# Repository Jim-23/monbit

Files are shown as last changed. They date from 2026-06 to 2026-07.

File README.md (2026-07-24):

# Monbit

A tiny ESP32-based digital monster pet with an e-ink display that evolves over time based on care, sleep cycles, and randomness.

<p align="center">
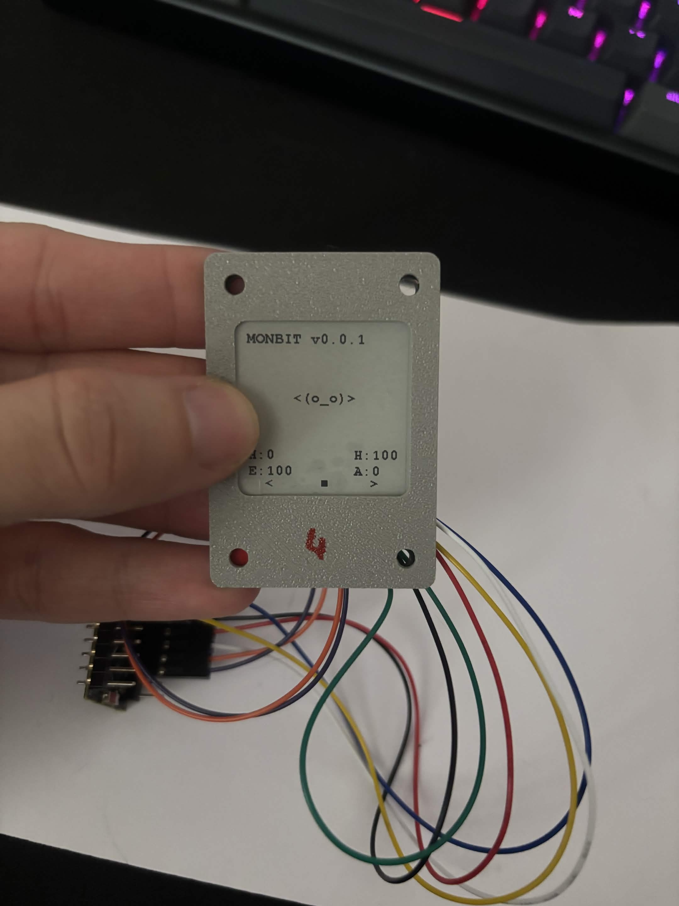
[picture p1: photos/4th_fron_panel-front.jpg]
Monbit front panel
  
</p>

## Motivation

Monbit is a personal project created to learn embedded development, hardware prototyping, and product design.

The goal is not only to create a device, but also to explore the full product development process. From firmware and electronics to CAD design and physical prototype.

I want to document the entire journey, sharing both successes and failures, to create a resource for others interested in similar projects.

---

### Documentation

- [Roadmap](./ROADMAP.md)
- [Development Log](./DEVLOG.md)
- [Hardware Notes](./hardware/hw-notes.md)
- [Game Design](./docs/game_design.md)
- [UI Design](./docs/ui_design.md)

## Current Progress

Current Version: `v0.0.4` (2026-07-13)

### Firmware
- [x] ESP32 bring-up
- [x] Project architecture (modular source files)
- [x] E-Ink display communication
- [x] Basic UI rendering
- [x] Partial display refresh
- [x] 3-button input system
- [x] Button debouncing
- [x] Monster state system
- [x] Monster actions (Feed / Play / Sleep)
- [x] Automatic monster tick system
- [x] Persistent storage (save/load)
- [x] Audio subsystem
- [x] Menu system
- [ ] Monster logic (name, personality, reactions)
- [ ] Battery management
- [ ] Deep sleep
- [ ] Sprite rendering

### Hardware
- [x] Components selected
- [x] ESP32 tested
- [x] E-Ink display tested
- [x] Buttons tested (breadboard)
- [x] First enclosure front prototype designed (front lid, far from final)
- [x] Audio amplifier connected
- [x] Speaker connected
- [ ] Battery integrated
- [ ] Charging module integrated
- [ ] Power switch integrated
- [ ] Accelerometer integrated
- [ ] Permanent wiring
- [ ] First fully assembled prototype
- [ ] Final enclosure designed

### Gameplay
- [x] Basic monster stats
- [x] Monster actions
- [x] Time-based stat changes
- [x] Beep when action is done
- [ ] Naming the monster
- [ ] Monster sprite and animations
- [x] Monster moods and states
- [ ] Growth/aging system
- [ ] Evolution
- [ ] Random events
- [ ] Game balancing

### Documentation
- [x] README
- [x] Roadmap
- [x] Devlog
- [x] Project versioning
- [ ] Wiring diagrams
- [ ] Hardware BOM
- [ ] Build instructions

## Milestones

### v0.0.1 — Hello Hardware

Completed:
- ESP32-C3 configured with PlatformIO
- USB serial debugging enabled
- E-Ink display connected and initialised
- First successful display render (`MONBIT v0.0.1`)

Update:
- basic GUI setup
- connected first button

### v0.0.2 — Buttons

Completed:
- Buttons are detected and affect                    the stats
  - LEFT button => eat
  - MIDDLE button => play
  - RIGHT button => sleep
- Screen has two options for refresh - full or partial
- When the button is pressed, the screen refreshes partially (without the big blink)
- Happiness renamed to Fun

### v0.0.3 - Storage

Completed:
- Every tick (currently 10 seconds), the hunger, fun and energy are changed by 1
- Every time the button is pressed, the current state of the Monster is saved to Flash
- When rebooted, the data is loaded

### v0.0.4 - Audio

Completed:
- Audio subsystem added
- Beep when button is pressed

### v0.0.5 - Menu

Completed:
- Menu system added
- Menu can be navigated with the buttons
- So far only mock settings are available in the menu (no actual functionality yet)

### v0.0.6 - Monster Logic

Completed:
- Moods and states were added
- Different monster visuals for the specific state/mood

## Hardware

Core components:

- ESP32-C3 SuperMini ?
- WeAct 1.54" E-Ink Display
- 500mAh LiPo Battery
- TP4056 USB-C Charging Module ?

- Tactile Buttons
- MAX98357A Audio Amplifier
- Speaker
- MPU6050 Accelerometer

## Software

Development environment:

- C++
- Arduino Framework
- PlatformIO
- Visual Studio Code

Libraries:

- GxEPD2
- FreeMonoBold0pt7bt
- i2s

## Gallery

### Wiring & Setup

<p align="center">
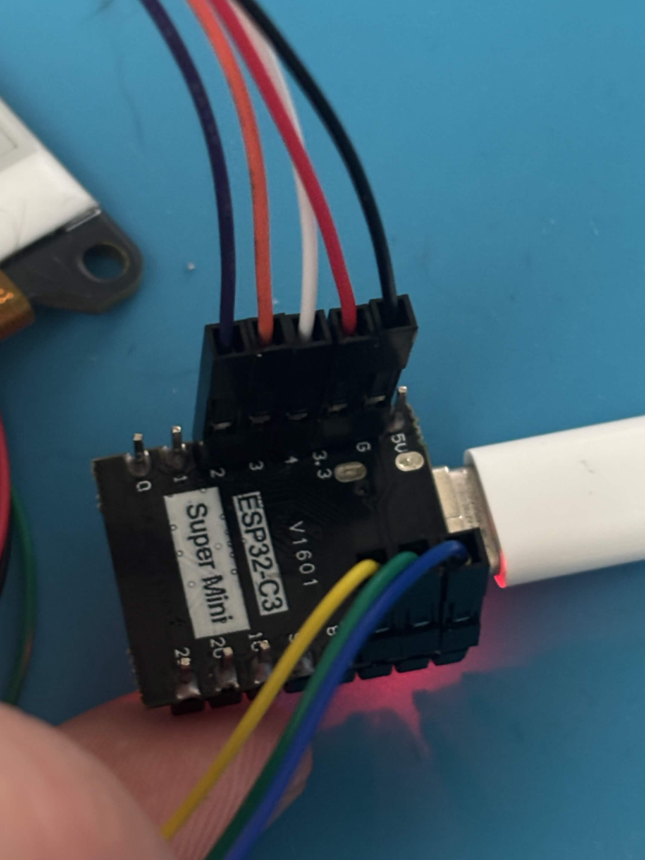
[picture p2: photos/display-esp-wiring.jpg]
ESP32 to e-ink display wiring
  
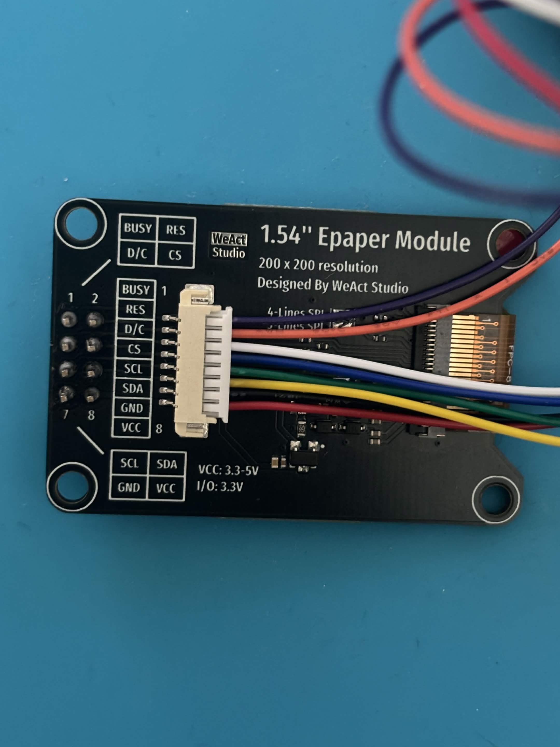
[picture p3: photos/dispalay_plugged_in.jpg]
Display plugged in
  
</p>
<p align="center">
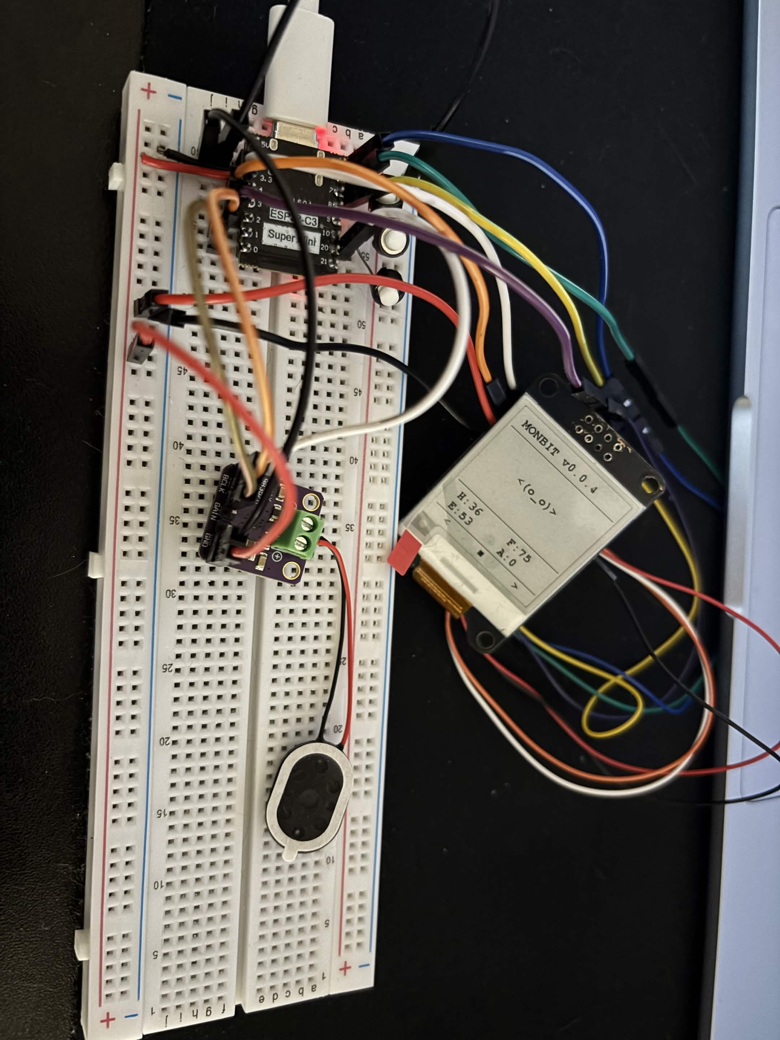
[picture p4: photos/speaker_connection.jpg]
Speaker connection (spaghetti monster has been created)
  
</p>

### Display & GUI

<p align="center">
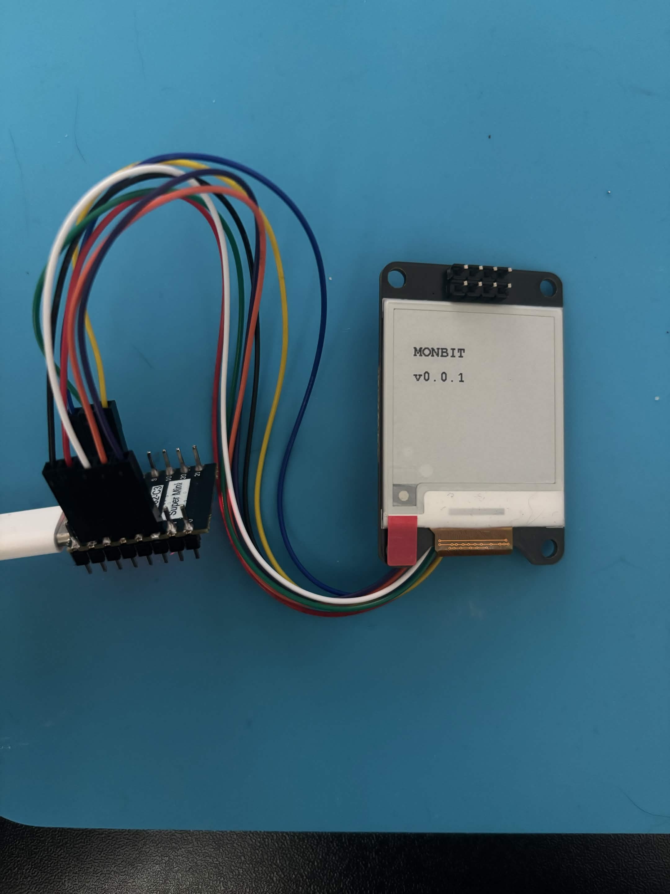
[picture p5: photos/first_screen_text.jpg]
First screen text render
  
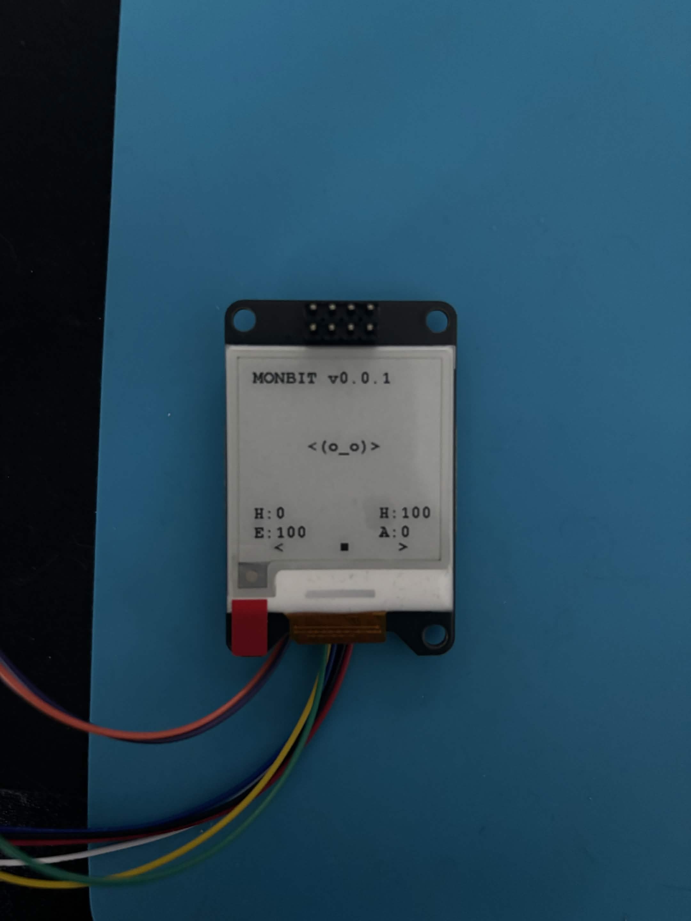
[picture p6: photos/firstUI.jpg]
First UI rendered on the e-ink display
  
</p>
<p align="center">
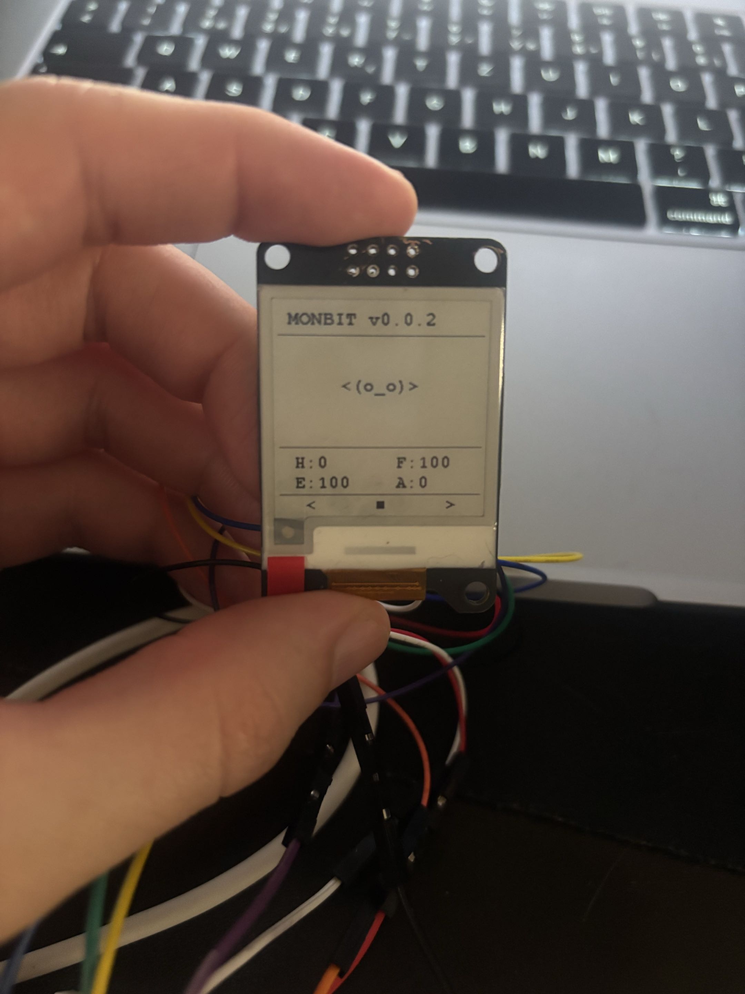
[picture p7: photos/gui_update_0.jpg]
GUI update
  
</p>
<p align="center">
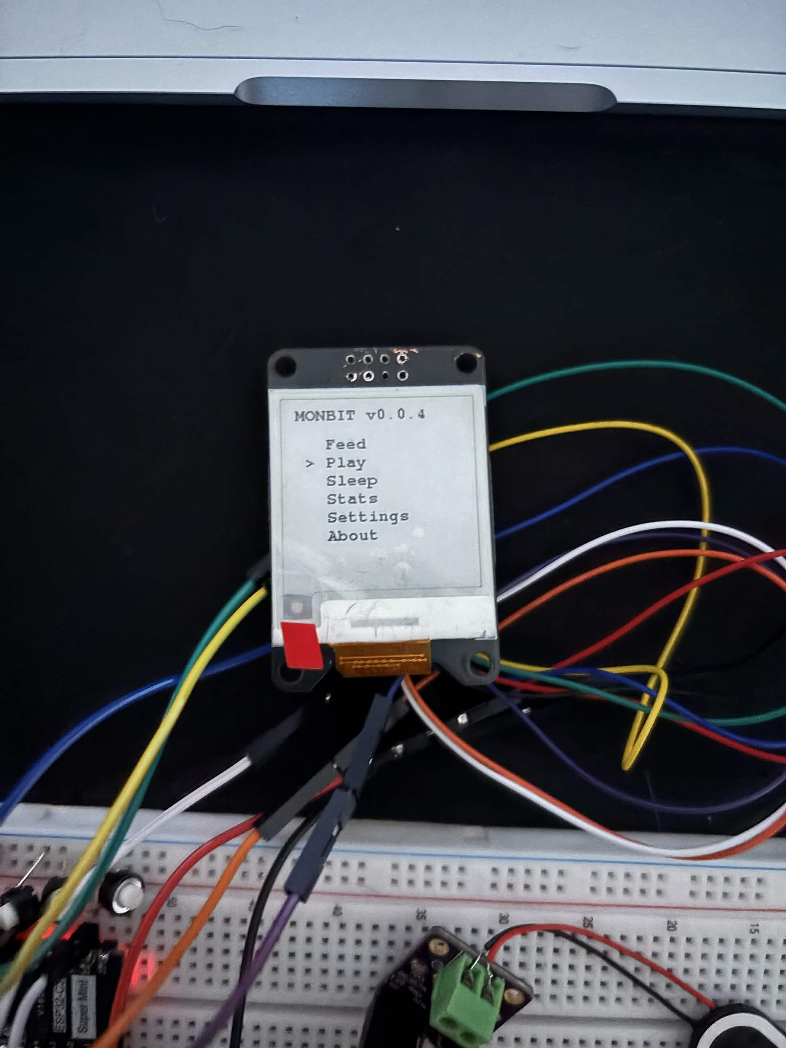
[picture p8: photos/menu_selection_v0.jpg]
Menu
  
</p>

### Buttons

<p align="center">
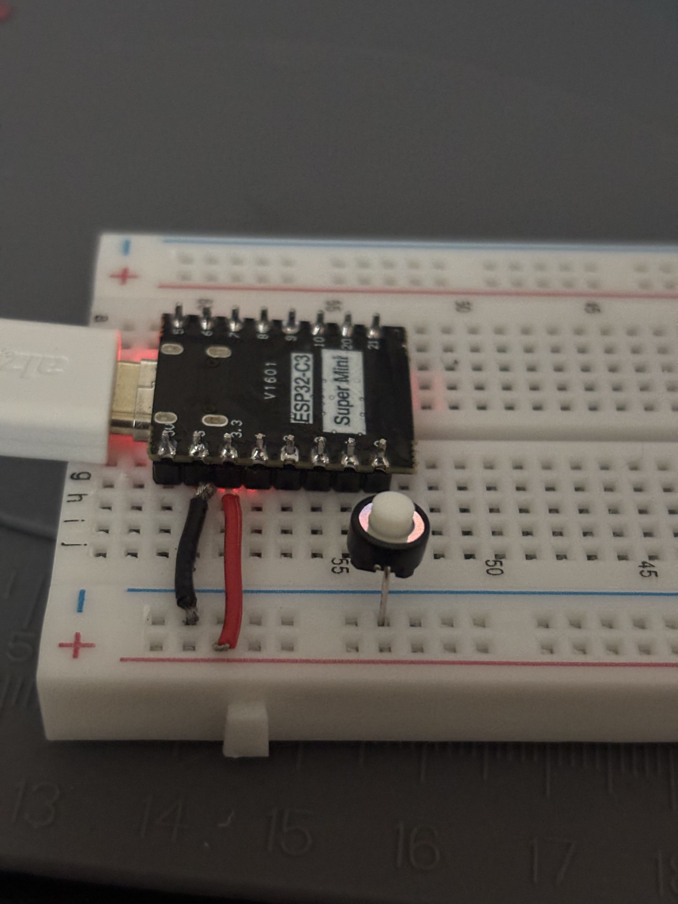
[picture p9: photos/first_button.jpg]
First button wired
  
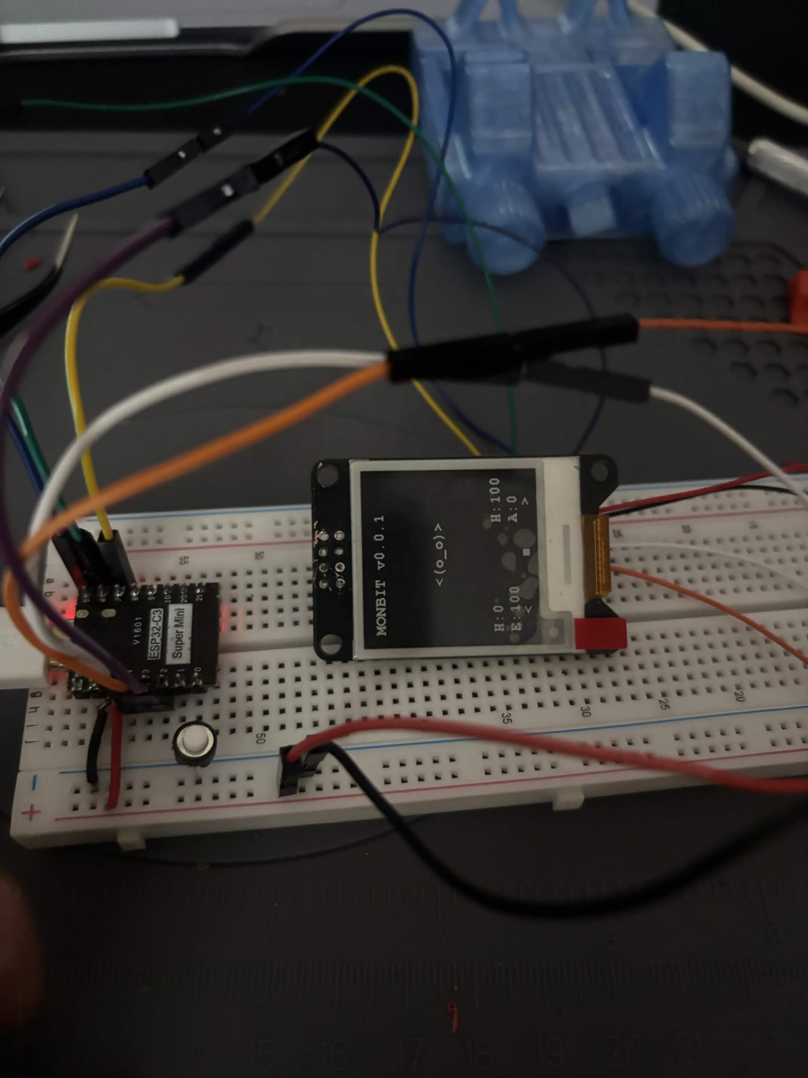
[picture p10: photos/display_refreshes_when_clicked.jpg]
Display refreshing on button click
  
</p>
<p align="center">
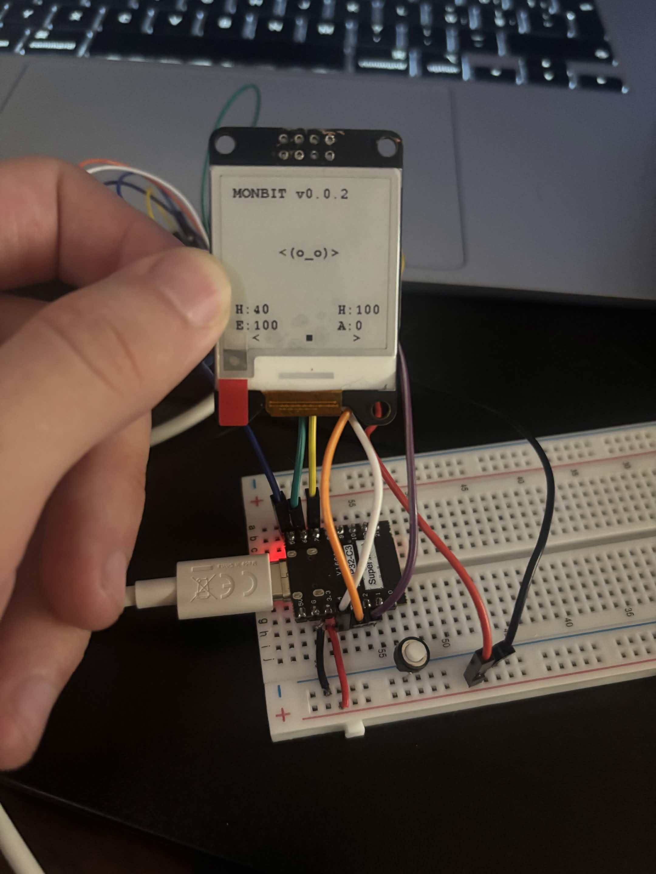
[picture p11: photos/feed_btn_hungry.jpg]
Feed button - hungry state
  
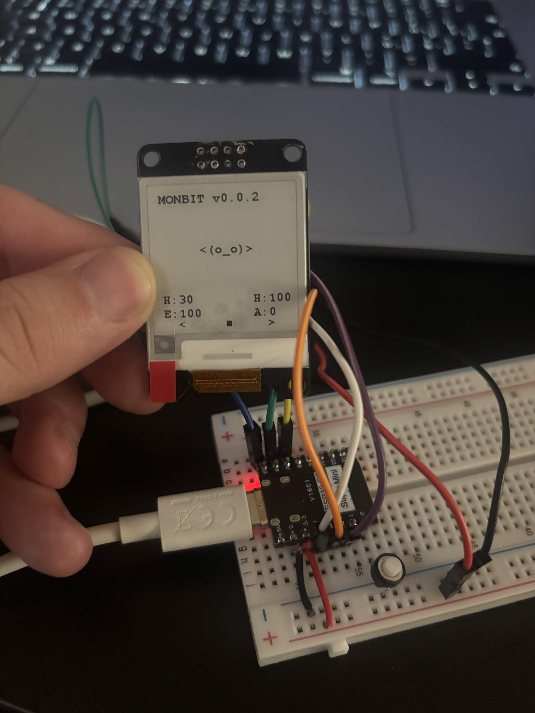
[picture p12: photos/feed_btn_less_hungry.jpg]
Feed button - less hungry state
  
</p>
<p align="center">
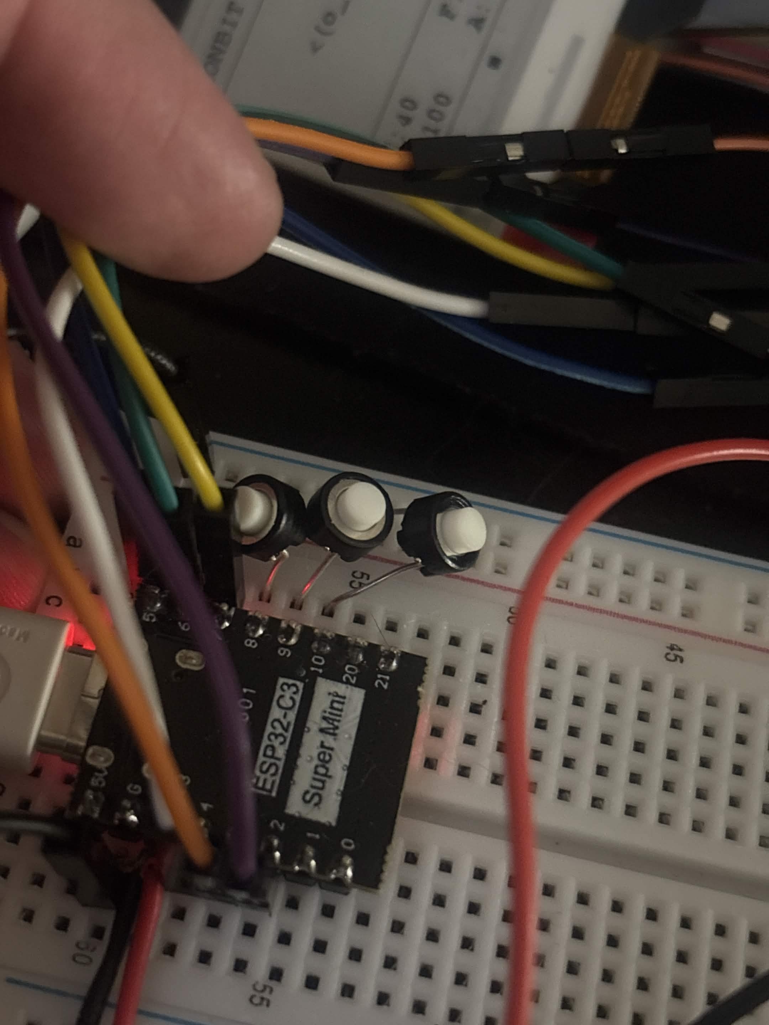
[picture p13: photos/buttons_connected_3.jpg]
Three buttons connected
  
</p>

### Enclosure

<p align="center">
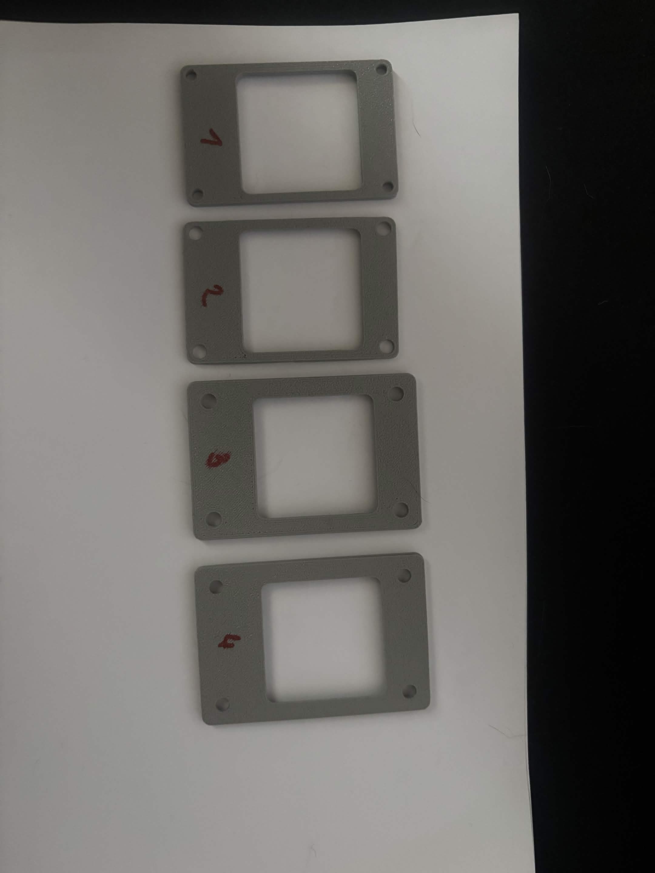
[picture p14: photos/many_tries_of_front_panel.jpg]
Multiple front panel iterations
  
</p>
<p align="center">
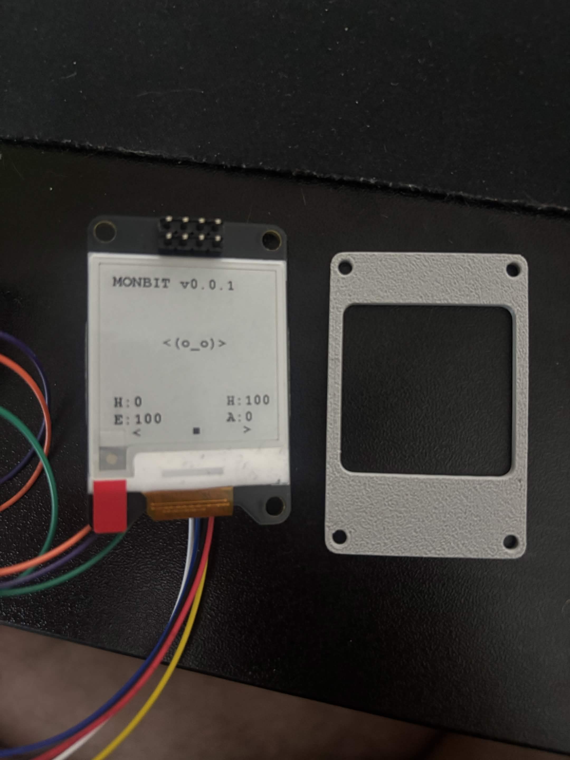
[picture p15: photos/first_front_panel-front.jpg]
First front panel - front
  
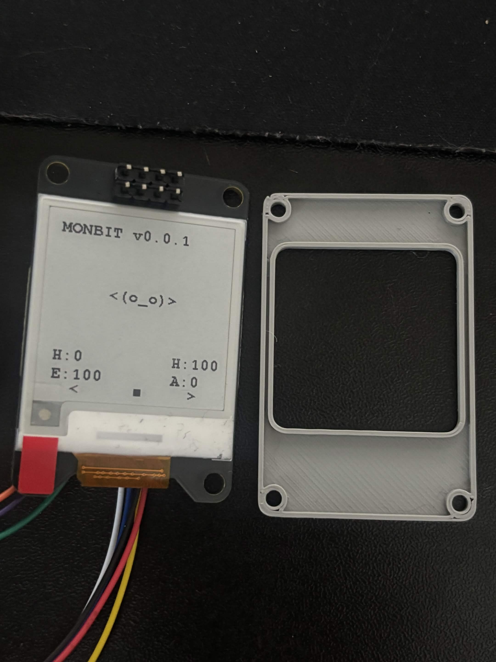
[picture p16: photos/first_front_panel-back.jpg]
First front panel - back
  
</p>
<p align="center">
  Front panel - front
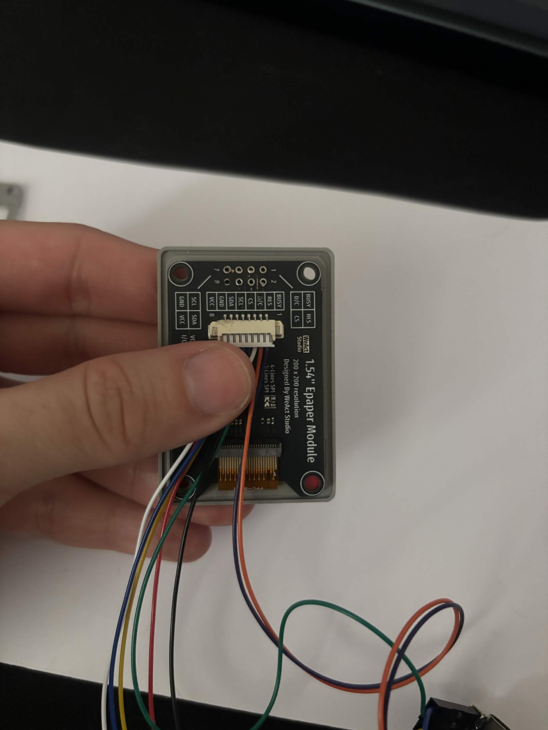
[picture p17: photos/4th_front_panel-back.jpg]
Front panel - back
  
</p>

## Repository Structure

```
monbit/
├── firmware/     # ESP32 firmware (PlatformIO)
│   ├── include/
│   ├── lib/
│   ├── src/
|   |   ├── debug/ # code used for debugging and testing
│   ├── test/
│   └── platformio.ini
├── hardware/     # Hardware notes & measurements
│   ├── hardware_notes.md
│   └── measurements.md
├── design/       # CAD files (enclosure STLs)
├── docs/         # Design notes
│   ├── game_design.md
│   └── ui_design.md
├── photos/       # Build & progress photos
├── DEVLOG.md
├── ROADMAP.md
├── LICENSE
└── README.md
```

---

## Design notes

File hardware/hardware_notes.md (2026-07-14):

# ESP32-C3 SuperMini

## ESP board pinout
ESP32-C3 SuperMini pinout

| Pin | Describtion | Connection |
|-----|---|---|
| 5V | 5V  | - |
| G | GND | Ground |
| 3V3 | 3.3V | Power |
| 4 | GPIO4 | Display DC |
| 3 | GPIO3 | Display RES |
| 2 | GPIO2 | Display BUSY |
| 1 | GPIO1 | Audio BCLK |
| 0 | GPIO0 | Audio DIN |
| 5 | GPIO5 | Display CS |
| 6 | GPIO6 | Display SCL |
| 7 | GPIO7 | Display SDA |
| 8 | GPIO8 | Left Button |
| 9 | GPIO9 | Middle Button |
| 10 | GPIO10 | Right Button |
| 20 | GPIO20 | Audio LRC (WS) |
| 21 | GPIO21 | - |

## Upload

Board:
esp32-c3-devkitm-1

Monitor speed:
115200

USB:
Works on macOS with data-capable USB-C cable

## Buttons - care for monster
| Button | ESP32-C3 |
|---|---|
| Left | GPIO8 |
| Middle | GPIO9 |
| Right | GPIO10 |
| Other Pin | GND |

## Display

Display:
WeAct 1.54" E-Paper

### Display Wiring to ESP

| WeAct E-Ink | ESP32-C3 |
|---|---|
| VCC | 3.3V |
| GND | GND |
| SDA | GPIO7 |
| SCL | GPIO6 |
| CS | GPIO5 |
| DC | GPIO4 |
| RES | GPIO3 |
| BUSY | GPIO2 |

PlatformIO:

build_flags =
    -DARDUINO_USB_MODE=1
    -DARDUINO_USB_CDC_ON_BOOT=1

Driver:

- GxEPD2_154_GDEY0154D67

SPI:

- SPI.begin(6, -1, 7, 5);

### Audio wiring to ESP

| MAX98357A | ESP32-C3 |
|---|---|
| VIN | 3.3V |
| GND | GND |
| DIN | GPIO0 |
| BCLK | GPIO1 |
| LRC (WS) | GPIO20 |
| SD | NC |
| GAIN | NC |
| SPK+ | Speaker + |
| SPK- | Speaker - |

#### Working Configuration

```cpp
Sample Rate          : 22050 Hz
Bits Per Sample      : 16-bit
DMA Buffer Count     : 8
DMA Buffer Length    : 512
Channel Format       : I2S_CHANNEL_FMT_RIGHT_LEFT
Communication Format : I2S_COMM_FORMAT_STAND_I2S
Waveform             : Sine
Amplitude            : 75%
```

> **Note:** 16000 Hz also produced clean audio, but 22050 Hz was selected as the project default.

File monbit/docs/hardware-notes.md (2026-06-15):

# ESP32-C3 SuperMini

## Upload

Board:
esp32-c3-devkitm-1

Monitor speed:
115200

USB:
Works on macOS with data-capable USB-C cable

## Display

Display:
WeAct 1.54" E-Paper

Pins:

VCC -> 3.3V
GND -> GND
SDA -> GPIO7
SCL -> GPIO6
CS -> GPIO5
D/C -> GPIO4
RES -> GPIO3
BUSY -> GPIO2

PlatformIO:

build_flags =
    -DARDUINO_USB_MODE=1
    -DARDUINO_USB_CDC_ON_BOOT=1

Driver:

GxEPD2_154_GDEY0154D67

SPI:

SPI.begin(6, -1, 7, 5);

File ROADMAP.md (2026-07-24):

# Roadmap

## 0.0.1 — Hello Hardware

### Goal

* ESP32 boots
* Serial prints work
* Display shows something

### Hardware

* ESP32-C3 Development Board (WiFi + Bluetooth)
* WeAct 1.54" E-Paper Module (SPI, Black/White)

### Done When

* Code uploads successfully
* Serial output works
* Display shows text or image

**Status:** Completed

---

## 0.0.2 — Input System

### Goal

* Wire buttons
* Wire power switch
* Detect button presses
* When button pressed, do something to monster (feed it for example)

Example Stats

* Hunger
* Fun
* Energy

### Hardware

* SKRGAED010 ALPS Tact Switch

### Done When
* Basic monster stats
* Simple interactions
  
* Buttons modify stats
* Display updates values

**Status:** Completed

---

## 0.0.3 — Basic monster + Memory System

### Goal:

- Monster state changes over time
- Save current state to flash
- Load state after reboot

### Done when:
- Power off device
- Power on device
- Monster stats are restored

Example:

* Hunger
* Fun
* Energy

**Status:** Completed

---

## 0.0.4 — Sound System

### Goal

* Play simple sounds
* Confirm actions with sound

### Hardware

* MAX98357A Audio Amplifier Module
* 15x3.5mm Mini Round Speaker 8Ω 0.5W

### Done When

* The device plays a beep sound upon boot
* Sound triggered by button press

**Status:** Completed

---

## 0.0.5 — UI and Menu System

### Goal
* Create a simple menu system
* Interactive menu
* Better layout and UX

### Done When
* Menu is displayed on the screen
* Menu can be navigated with buttons
* Buttons are changed to Left Middle Right

## 0.0.6 — Monster Logic

### Goal
* Monster has a name
* Monster has a personality, moods and states
* Monster logic is implemented and the monster reacts to user actions
* Monster changes whhen mood/state changes

---
## 0.0.7 — Battery integration

### Goal
* The battery powers the device
* Device can charge via USB-C
* Device can run on battery power

### Hardware
* Li-Po Battery 503035 500mAh 3.7V JST-PH 2.0
* USB-C TP4056 Lithium Battery Charger Module

### Done When
* Integrate Li-Po battery
* Integrate charging circuit
* Read battery voltage
* Display battery level

**Status:** Work in Progress

---

## 0.0.8 — Power Optimization 

### Goal

* Deep sleep support
* Wake on button press
* Switch to turn device on/off

### Done When

* Device sleeps automatically
* Button wakes the device

---
## 0.0.9 — Accelerometer Integration

### Goal
* Detect device orientation
* Detect device movement

### Hardware
* MPU6050 Accelerometer
  
### Done When
* Device detects orientation changes
* When device is moved, it reacts (e.g., wakes up, changes state, etc.)

---

## 0.0.10 — UI & Animation

### Goal

* Draw monster sprites
* Add simple animations

### Done When

* Monster is animated
* Status icons are displayed
* UI resembles the final design
  
---

## 0.0.11 — First real monster

### Goal

* Monster has a name
* Monster has a personality
* Monster has a unique appearance

### Done When

* Specific monster displays on the screen
* Monster sprite is loaded

---

## 0.0.12 — Hardware Assembly

### Goal

* All components are wired together and works without breadboard

---
## 0.0.13 — Enclosure

### Goal
* 3D printed enclosure back and front
* Enclosure holds all components
* Enclosure has holes for buttons, display, and speaker

### Done When
* All components fit inside the enclosure
* Buttons are accessible
* Display is securely mounted
* USB-C port is accessible
* Speaker opening is present

---

## 0.1.0 — First Prototype

### Goal

* Fully assembled device
* 3D printed enclosure
* Stable hardware

### Done When

* Portable device
* Battery powered
* Fully functional

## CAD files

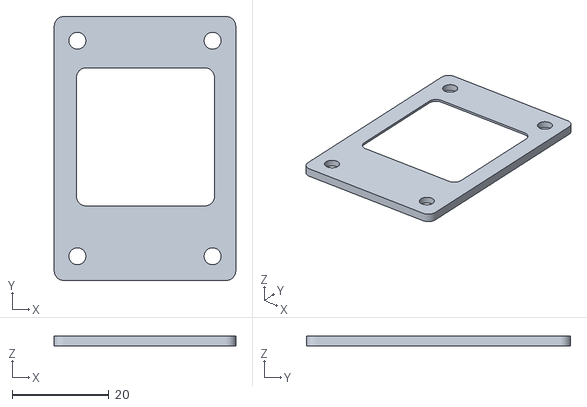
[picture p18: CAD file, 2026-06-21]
design/top_v0.0.4.stl
37.5 x 54.5 x 2.00

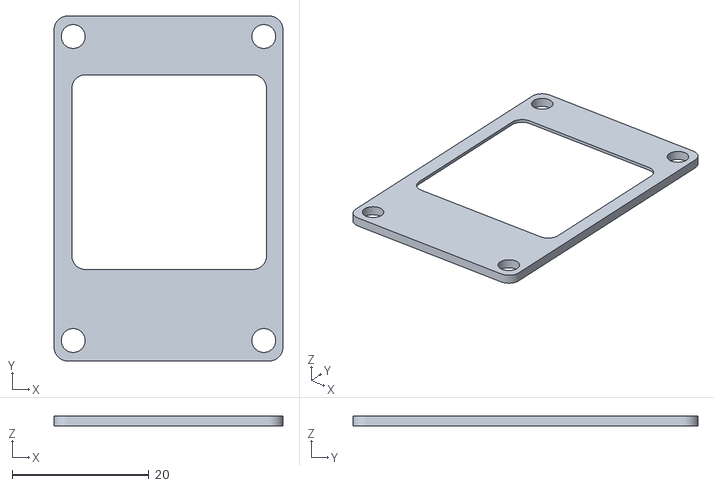
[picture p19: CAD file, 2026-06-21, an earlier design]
design/top_v0.0.2.stl
33.5 x 50.5 x 1.50

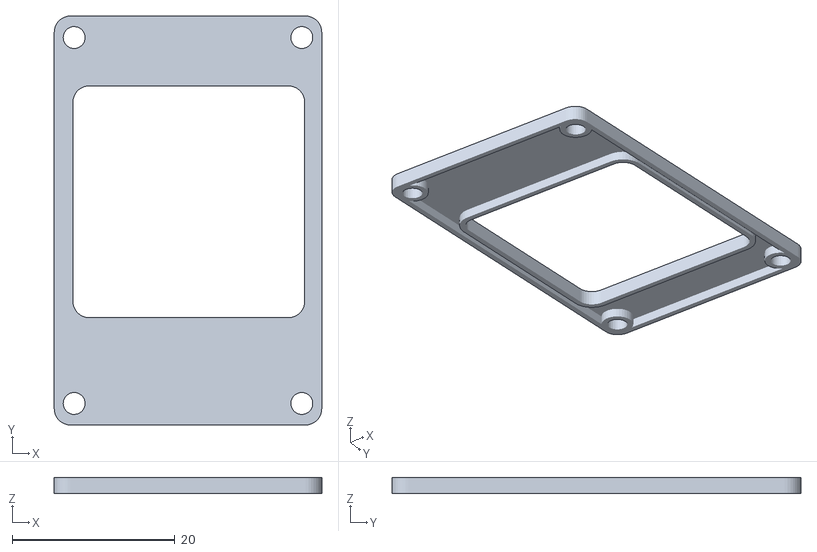
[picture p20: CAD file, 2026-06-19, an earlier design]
design/top_v0.0.1.stl
32.9 x 50.3 x 2.00

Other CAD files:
design/top_v0.0.3.stl

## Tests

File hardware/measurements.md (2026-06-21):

## Measurments:
- always as width x height x depth in mm

### Display board

#### PCB area
- 32.8 x 50 x 6.3 mm
    - the depth is with the display connector

**Hole for screws**
- d = 3.5 mm
- from the edges of PCB: 1 mm

#### Display area (the whole display)
- 31.8 x 37.5 mm

#### Visible screen area
- 28 x 28 mm 

#### Other
- from top/bottom of the board to top/bottom of the display:
    - 6.5 mm

- top of the display to top of the screen (same for left and right):
    - 1.5 mm

- bottom of the display to bottom of the screen:
    - 7.5 mm

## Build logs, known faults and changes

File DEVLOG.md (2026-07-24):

## Development Log

### v0.0.1
- ESP32 configured
- E-Ink display working
- First UI rendered

ESP32 to display wiring
- yes I know, I have soldered pins in a wrong direction (fixed it later)

Display plugged in
First screen text
First UI rendered

### Front lid

Many tries of the front panel

#### Front lid Prototype 1 (18.6.2026)
- First enclosure top cover printed
- Learned enclosure is too small for PCB
- Screw holes tested, quite small

First front panel - front
First front panel - back

#### Front lid Prototype 2 (19.6.2026)
- Fits well, but it sits on top of the PCB, needs to be made slightly over the edge

#### Front lid Prototype 3 (19.6.2026)
- Fits well, but still I need to adjust the "back" part to have a good grid for the PCB + edges

#### Front lid Prototype 4 (19.6.2026)
- almost perfect, maybe will adjust the site a bit more
- In the future, I might make it deeper

Fourth front panel - front
Fourth front panel - back

#### First button (21.6.2026)
- first button input succeeded!
- and don't forget, BUTTONS HAVE ORIENTATION!

BUTTON PRESSED
BUTTON RELEASED

First button - works

- then I conected the display as well and added a function which refreshes the display
- when I know clikc on the button, the screen refreshes
Display refresh

### v.0.0.2
- first button connected to pin 0
- gui refreshment
- renamed happiness to fun so in gui is displayed F instead of second H

#### Button functions (27.6.2026)
- the button now feeds the monster by 10 until its back to 0

Button State - hungry
Button State - less hungry

#### New GUI
- I have updated the gui to look a bit cleaner and polished, obviously its not final yet
- I had to also rename happines to fun so there are not 2 H displayed, it was quite confusing
    - I am considering to change it later to something like HUN, ENG, FUN, AGE or just use icons

New GUI

#### Update
- I have connected two more buttons and added them on pins 8, 9 and 10
- Feed button was removed and function in code as well, currently the code only prints out which button was pressed
    - LEFT
    - MIDDLE
    - RIGHT
- later, I might add more buttons, but currently this works fine
    - the breadboard is a mess, I know, but it will eventually be better.
    3 Buttons
- added interaction with gui when button is pressed, for example
    - press left button => feed the Monster, 
        - hunger is decreased by 10
    - press middle button => play with the Monster
        - fun is increased by 10
        - hunger is increased by 10
        - energy is decreaased by 5
    - press right button => Monster sleeps
        - fun is decreased by 5
        - hunger is increased by 5
        - energy is increased by 10

### v.0.0.3 (28.6.2026)
- Added flash storage system
- It was quite easy actually so I am happy for that
- Saving is performed after a button is pressed
- Would like to also add an autosave every 5 minutes

### v0.0.4 (11.07.2026)

#### Audio System

- Soldered speaker to MAX98357A amplifier.
- Wired amplifier to ESP32-C3.
- Created audio module (audio.hpp and audio.cpp).
- The speaker produces buzz instead of clear tone and I have no idea why, maybe wrong I2C config
- Wiring to ESP:

    | MAX98357A | ESP32-C3 |
    |------------|----------|
    | VIN | 3.3V |
    | GND | GND |
    | DIN | GPIO0 |
    | BCLK | GPIO1 |
    | LRC (WS) | GPIO20 |
    | SD | - |
    | GAIN | -|
    | SPK+ | Speaker + |
    | SPK- | Speaker - |

#### Update (13.07.2026)
- finally managed to implement clear sound with a specific configuration
- the problem was not the HW but the config for the audio, wiring can stay as it is
- you can hear one beep sound when you power the device
Speaker connection + spaghetti monster

### v0.0.5 (14.07.2026)
- I have decided to switch to a new ESP32 module, the ESP32-S3 mostly because of more GPIO pins which I will need for accelerometer. 
  - Currently waiting for the module to arrive (approx. 2 weeks)

#### UI and Menu System
- added basic menu when middle button is pressed
- user can navigate using left button, right button and middle button to confirm
What's on menu for today?

#### Update (24.07.2026)
- I have added more polished menu system and made the code more readable and organized
- Settings are still mock, but I will implement them later - the user should be able to turn off the sound and change Monster name
- Next focus is monster logic

### v0.0.6 (24.07.2026)
- I have added basic monster logic, the monster has different states and moods
- There are few different options
- States:
  - None,
  - Playing,
  - Eating,
  - Sleeping,
  - Dizzy,
  - Sick,
  - Injured,
  - Dead,
- Moods:
  - Happy,
  - Normal,
  - Hungry,
  - Tired,
  - Bored,
  - Sad,
  - Critical
- Currently it needs to be tested, but not all of them are implemented, for example Dizzy logic will be added when accelerometer is added

#### Update
- I am trying to add species, starting with slime, Blob

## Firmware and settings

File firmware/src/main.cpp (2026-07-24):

#include <Arduino.h>

#include <GxEPD2_BW.h>
#include <Fonts/FreeMonoBold9pt7b.h>

#include "monster.hpp"
#include "ui.hpp"
#include "input.hpp"
#include "storage.hpp"
#include "audio.hpp"

// BUSY, RST, DC, CS
GxEPD2_BW<GxEPD2_154_GDEY0154D67,
          GxEPD2_154_GDEY0154D67::HEIGHT> display(
    GxEPD2_154_GDEY0154D67(5, 4, 3, 2));

Monster monster;
Screen current_screen = Screen::Home;
int selected_menu = 0;

constexpr int MENU_ITEM_COUNT = 6;
bool needs_refresh = false;

constexpr unsigned long TICK_INTERVAL_MS = 10000;
unsigned long last_tick_ms = 0;

enum class RefreshMode
{
    Full,
    Partial
};

void refresh_display(RefreshMode mode)
{
    if (mode == RefreshMode::Full)
    {
        display.setFullWindow();
    }
    else
    {
        display.setPartialWindow(
            0,
            0,
            display.width(),
            display.height());
    }

    display.firstPage();

    do
    {
        draw_screen(monster, current_screen, selected_menu);
    }
    while (display.nextPage());

    Serial.println("Display updated");
}

void update_monster()
{
    const unsigned long now = millis();

    if (now - last_tick_ms >= TICK_INTERVAL_MS)
    {
        monster.tick();
        last_tick_ms = now;

        if (current_screen == Screen::Home)
            needs_refresh = true;

        Serial.println("Monster tick");
    }
}

void change_screen(Screen screen)
{
    current_screen = screen;
    needs_refresh = true;
}

void menu_previous()
{
    selected_menu--;

    if (selected_menu < 0)
        selected_menu = MENU_ITEM_COUNT - 1;
}

void menu_next()
{
    selected_menu++;

    if (selected_menu >= MENU_ITEM_COUNT)
        selected_menu = 0;
}

void handle_home_input(Button button)
{
    if (button == Button::Middle)
    {
        selected_menu = 0;
        change_screen(Screen::Menu);
    }
}

void execute_selected_menu()
{
    switch (selected_menu)
    {
        case MENU_FEED:
            if (monster.feed())
            {
                audio::play_feed();
                save_monster(monster);
            }

            change_screen(Screen::Home);
            break;

        case MENU_PLAY:
            if (monster.play())
            {
                audio::play_play();
                save_monster(monster);
            }

            change_screen(Screen::Home);
            break;

        case MENU_SLEEP:
            if (monster.sleep())
            {
                audio::play_sleep();
                save_monster(monster);
            }

            change_screen(Screen::Home);
            break;

        case MENU_STATS:
            change_screen(Screen::Stats);
            break;

        case MENU_SETTINGS:
            change_screen(Screen::Settings);
            break;

        case MENU_ABOUT:
            change_screen(Screen::About);
            break;
    }
}

void handle_menu_input(Button button)
{
    switch (button)
    {
        case Button::Left:
            menu_previous();
            needs_refresh = true;
            break;

        case Button::Right:
            menu_next();
            needs_refresh = true;
            break;

        case Button::Middle:
            execute_selected_menu();
            break;

        default:
            break;
    }
}

void handle_settings_input(Button button)
{
    if (button == Button::Middle)
    {
        change_screen(Screen::Home);
    }
}

void handle_about_input(Button button)
{
    if (button == Button::Middle)
    {
        change_screen(Screen::Home);
    }
}

void refresh_if_needed()
{
    if (!needs_refresh)
        return;

    refresh_display(RefreshMode::Partial);

    needs_refresh = false;
}

void handle_stats_input(Button button)
{
    if (button == Button::Middle)
    {
        change_screen(Screen::Home);
    }
}

void handle_input()
{
    const Button button = poll_buttons();

    if (button == Button::None)
        return;

    switch (current_screen)
    {
        case Screen::Home:
            handle_home_input(button);
            break;

        case Screen::Menu:
            handle_menu_input(button);
            break;

        case Screen::Stats:
            handle_stats_input(button);
            break;

        case Screen::Settings:
            handle_settings_input(button);
            break;

        case Screen::About:
            handle_about_input(button);
            break;
    }
}

void setup()
{
    Serial.begin(115200);
    Serial.println("=== MONBIT ===");

    SPI.begin(6, -1, 7, 5);

    input_init();

    display.init(115200);
    display.setRotation(0);

    if (!audio::init())
    {
        Serial.println("Audio initialization failed");
    }

    if (!load_monster(monster))
    {
        monster.create_random();
        save_monster(monster);
    }

    change_screen(Screen::Home);
    refresh_display(RefreshMode::Full);

    audio::play_startup();
}

void loop()
{

    update_monster();
    handle_input();
    refresh_if_needed();

}

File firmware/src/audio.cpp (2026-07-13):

#include "audio.hpp"

#include <Arduino.h>
#include <driver/i2s.h>
#include <math.h>

namespace
{
    constexpr i2s_port_t I2S_PORT = I2S_NUM_0;

    constexpr gpio_num_t PIN_BCLK = GPIO_NUM_1;
    constexpr gpio_num_t PIN_LRC  = GPIO_NUM_20;
    constexpr gpio_num_t PIN_DIN  = GPIO_NUM_0;

    constexpr uint32_t SAMPLE_RATE = 22050;

    constexpr uint8_t DMA_BUFFER_COUNT = 8;
    constexpr uint16_t DMA_BUFFER_LENGTH = 512;

    constexpr int WRITE_CHUNK_FRAMES = 256;

    struct StereoFrame
    {
        int16_t left;
        int16_t right;
    };

    int16_t generate_sample(float phase)
    {
        return static_cast<int16_t>(
            sinf(2.0f * static_cast<float>(M_PI) * phase) * 32767.0f);
    }
}

bool audio::init()
{
    i2s_driver_uninstall(I2S_PORT);

    i2s_config_t config = {
        .mode = (i2s_mode_t)(I2S_MODE_MASTER | I2S_MODE_TX),
        .sample_rate = SAMPLE_RATE,
        .bits_per_sample = I2S_BITS_PER_SAMPLE_16BIT,
        .channel_format = I2S_CHANNEL_FMT_RIGHT_LEFT,
        .communication_format = I2S_COMM_FORMAT_STAND_I2S,
        .intr_alloc_flags = 0,
        .dma_buf_count = DMA_BUFFER_COUNT,
        .dma_buf_len = DMA_BUFFER_LENGTH,
        .use_apll = false,
        .tx_desc_auto_clear = true,
        .fixed_mclk = 0
    };

    i2s_pin_config_t pins = {
        .bck_io_num = PIN_BCLK,
        .ws_io_num = PIN_LRC,
        .data_out_num = PIN_DIN,
        .data_in_num = I2S_PIN_NO_CHANGE
    };

    if (i2s_driver_install(I2S_PORT, &config, 0, nullptr) != ESP_OK)
    {
        Serial.println("Audio: driver install failed");
        return false;
    }

    if (i2s_set_pin(I2S_PORT, &pins) != ESP_OK)
    {
        Serial.println("Audio: pin configuration failed");
        return false;
    }

    Serial.println("Audio initialized");
    return true;
}

void audio::beep(uint16_t frequency, uint16_t duration_ms)
{
    const float phase_increment =
        static_cast<float>(frequency) / SAMPLE_RATE;

    const int total_frames =
        static_cast<int>((uint64_t)SAMPLE_RATE * duration_ms / 1000);

    StereoFrame chunk[WRITE_CHUNK_FRAMES];

    int written_frames = 0;

    while (written_frames < total_frames)
    {
        int frames_this_chunk = total_frames - written_frames;

        if (frames_this_chunk > WRITE_CHUNK_FRAMES)
        {
            frames_this_chunk = WRITE_CHUNK_FRAMES;
        }

        for (int i = 0; i < frames_this_chunk; i++)
        {
            float phase = fmodf(
                (written_frames + i) * phase_increment,
                1.0f);

            int16_t value =
                static_cast<int16_t>(generate_sample(phase) * 0.75f);

            chunk[i] = { value, value };
        }

        size_t bytes_written;

        i2s_write(
            I2S_PORT,
            chunk,
            frames_this_chunk * sizeof(StereoFrame),
            &bytes_written,
            portMAX_DELAY);

        written_frames += frames_this_chunk;
    }
}

void audio::play_startup()
{
    beep(440, 80);
    delay(20);

    beep(660, 80);
    delay(20);

    beep(880, 120);
}

void audio::play_feed()
{
    beep(900, 60);
}

void audio::play_play()
{
    beep(700, 70);
    delay(20);

    beep(900, 70);
}

void audio::play_sleep()
{
    beep(220, 180);
}

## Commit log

2026-05-31 feat: esp32 boot
2026-05-31 feat: enable USB CDC serial on ESP32-C3
2026-06-01 Add battery and USB-C charging information to README
    Updated README to include battery and charging details.
2026-06-15 feat: adds wiring specification
2026-06-21 add ws stl files
    [top_v0.0.2.stl, top_v0.0.3.stl, top_v0.0.4.stl]
2026-06-21 Revise DEVLOG with front lid prototype updates
    Updated hardware prototype details for front lid versions.
2026-06-21 Add notes about front lid prototype to DEVLOG
2026-06-21 update of structure, add measurments
    [top_v0.0.1.stl, top_v0.0.2.stl, top_v0.0.3.stl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]
2026-06-21 First button handling
2026-06-21 Added refresh function to display when button is pressed
2026-06-27 feat: first button functionality - feed button: feed the monster by 10 when pressed until its full
2026-06-27 feat: update for buttons
    - 3 buttons are now specified - LEFT, MIDDLE, RIGHT
    - each button logs which one it is when pressed
    - updated docs and added photo of the buttons
2026-06-27 feat: add 3 button interaction system
2026-07-13 feat: change of sample rate, to be tested
2026-07-14 feat: update of docs, add reaction to button press
2026-07-17 Update DEVLOG
    Added details about the new ESP32-S3 module and updated the UI and Menu System section with new features.
